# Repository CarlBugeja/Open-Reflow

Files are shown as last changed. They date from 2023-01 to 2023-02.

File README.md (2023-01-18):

# Open-Reflow-Controller-Self-Reflow-PCB-
Shield: [][cc-by-sa]
A controller for self-reflowing PCBs
This work is licensed under a
[Creative Commons Attribution-ShareAlike 4.0 International License][cc-by-sa].

[][cc-by-sa]

[cc-by-sa]: http://creativecommons.org/licenses/by-sa/4.0/
[cc-by-sa-image]: https://licensebuttons.net/l/by-sa/4.0/88x31.png
[cc-by-sa-shield]: https://img.shields.io/badge/License-CC%20BY--SA%204.0-lightgrey.svg

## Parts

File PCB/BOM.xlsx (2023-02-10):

Comment | Description | Designator | Footprint | LibRef | Quantity
UBC1H470MNS1GS |  | C1 | UBC1H470MNS1GS | UBC1H470MNS1GS | 1
22uF |  | C2 | CAPAE4343X55M | CAP* | 1
10nF |  | C3, C6, C13, C15 | RESC1608X04N | CAP | 4
100nF |  | C4, C5, C7, C9, C12, C14, C16 | RESC1608X04N | CAP | 7
1uF |  | C8 | RESC1608X04N | CAP | 1
12pF |  | C10, C11 | RESC1608X04N | CAP | 2
'LTST-C190KFKT |  | D1, D2 | RESC1608X04N | LED | 2
691508110302 | Serie 5081 - 3.50 mm Horizontal Entry SMT with Rising Cage Clamp WR-TBL, 2 pin | H2, H3 | 691508110302 | CMP-1502-02490-1 | 2
10118193-0001LF | Micro USB B Type Receptacle, -55 to 85 degC, 5-Pin SMD, RoHS, Tape and Reel | J1 | FCI-10118193-0001LF-5_V | CMP-2000-05119-1 | 1
LI0805H151R-10 | Chip Beads for Signal Filtering, 0.15 Ohms, -40 to 125 degC, 2-Pin SMD, RoHS, Tape and Reel | L1, L2 | LIRD-LI0805H151R-10-2_V | CMP-2000-05195-1 | 2
BSC0906NS | N-Channel OptiMOS Power-MOSFET, 30 V VDS, 63 A ID, -55 to 150 degC, PG-TDSON-8-1, Reel, Green | Q1 | INF-PG-TDSON-8-1_V | CMP-1090-00064-1 | 1
22 |  | R1, R3 | RESC1608X04N | RES | 2
150 |  | R2, R4 | RESC1608X04N | RES | 2
100 |  | R5, R9, R13 | RESC1608X04N | RES | 3
10k |  | R6, R7, R8, R10 | RESC1608X04N | RES | 4
DNP | 'RC0402JR-0710KL | R11, R12 | RESC1005X40X25ML5T10 | CMP-2002-07915-2 | 2
PTS815 SJK 250 SMTR LFS |  | SW1, SW2 | PTS815 SJK 250 SMTR LFS | PTS815 SJK 250 SMTR LFS | 2
TL750M05CKVURG3 | Single Output LDO, 750 mA, Fixed 5 V Output, 6 to 26 V Input, with Low IQ, 3-pin PFM (KVU), 0 to 125 degC, Green (RoHS & no Sb/Br) | U1 | KVU0003A_M | CMP-0395-01077-2 | 1
ATmega32U4-AU | 8-bit AVR Microcontroller, 2.7-5.5V, 16MHz, 32KB Flash, 1KB EEPROM, 2.5KB SRAM, USB Controller, 44-pin TQFP, Industrial Grade (-40°C to 85°C), Ext Osc | U2 | 44ML_M | CMP-0095-00285-2 | 1
MCP9600-E/MX | IC THERMOCOUPLE TO I2C 20MQFN | U3 | FP-C04-186-MFG | CMP-06290-000001-1 | 1
TSX-3225 16.0000MF09Z-AC0 | CRYSTAL 16.0000MHZ 9PF SMD | Y1 | FP-TSX-3225-MFG | CMP-36405-000014-1 | 1

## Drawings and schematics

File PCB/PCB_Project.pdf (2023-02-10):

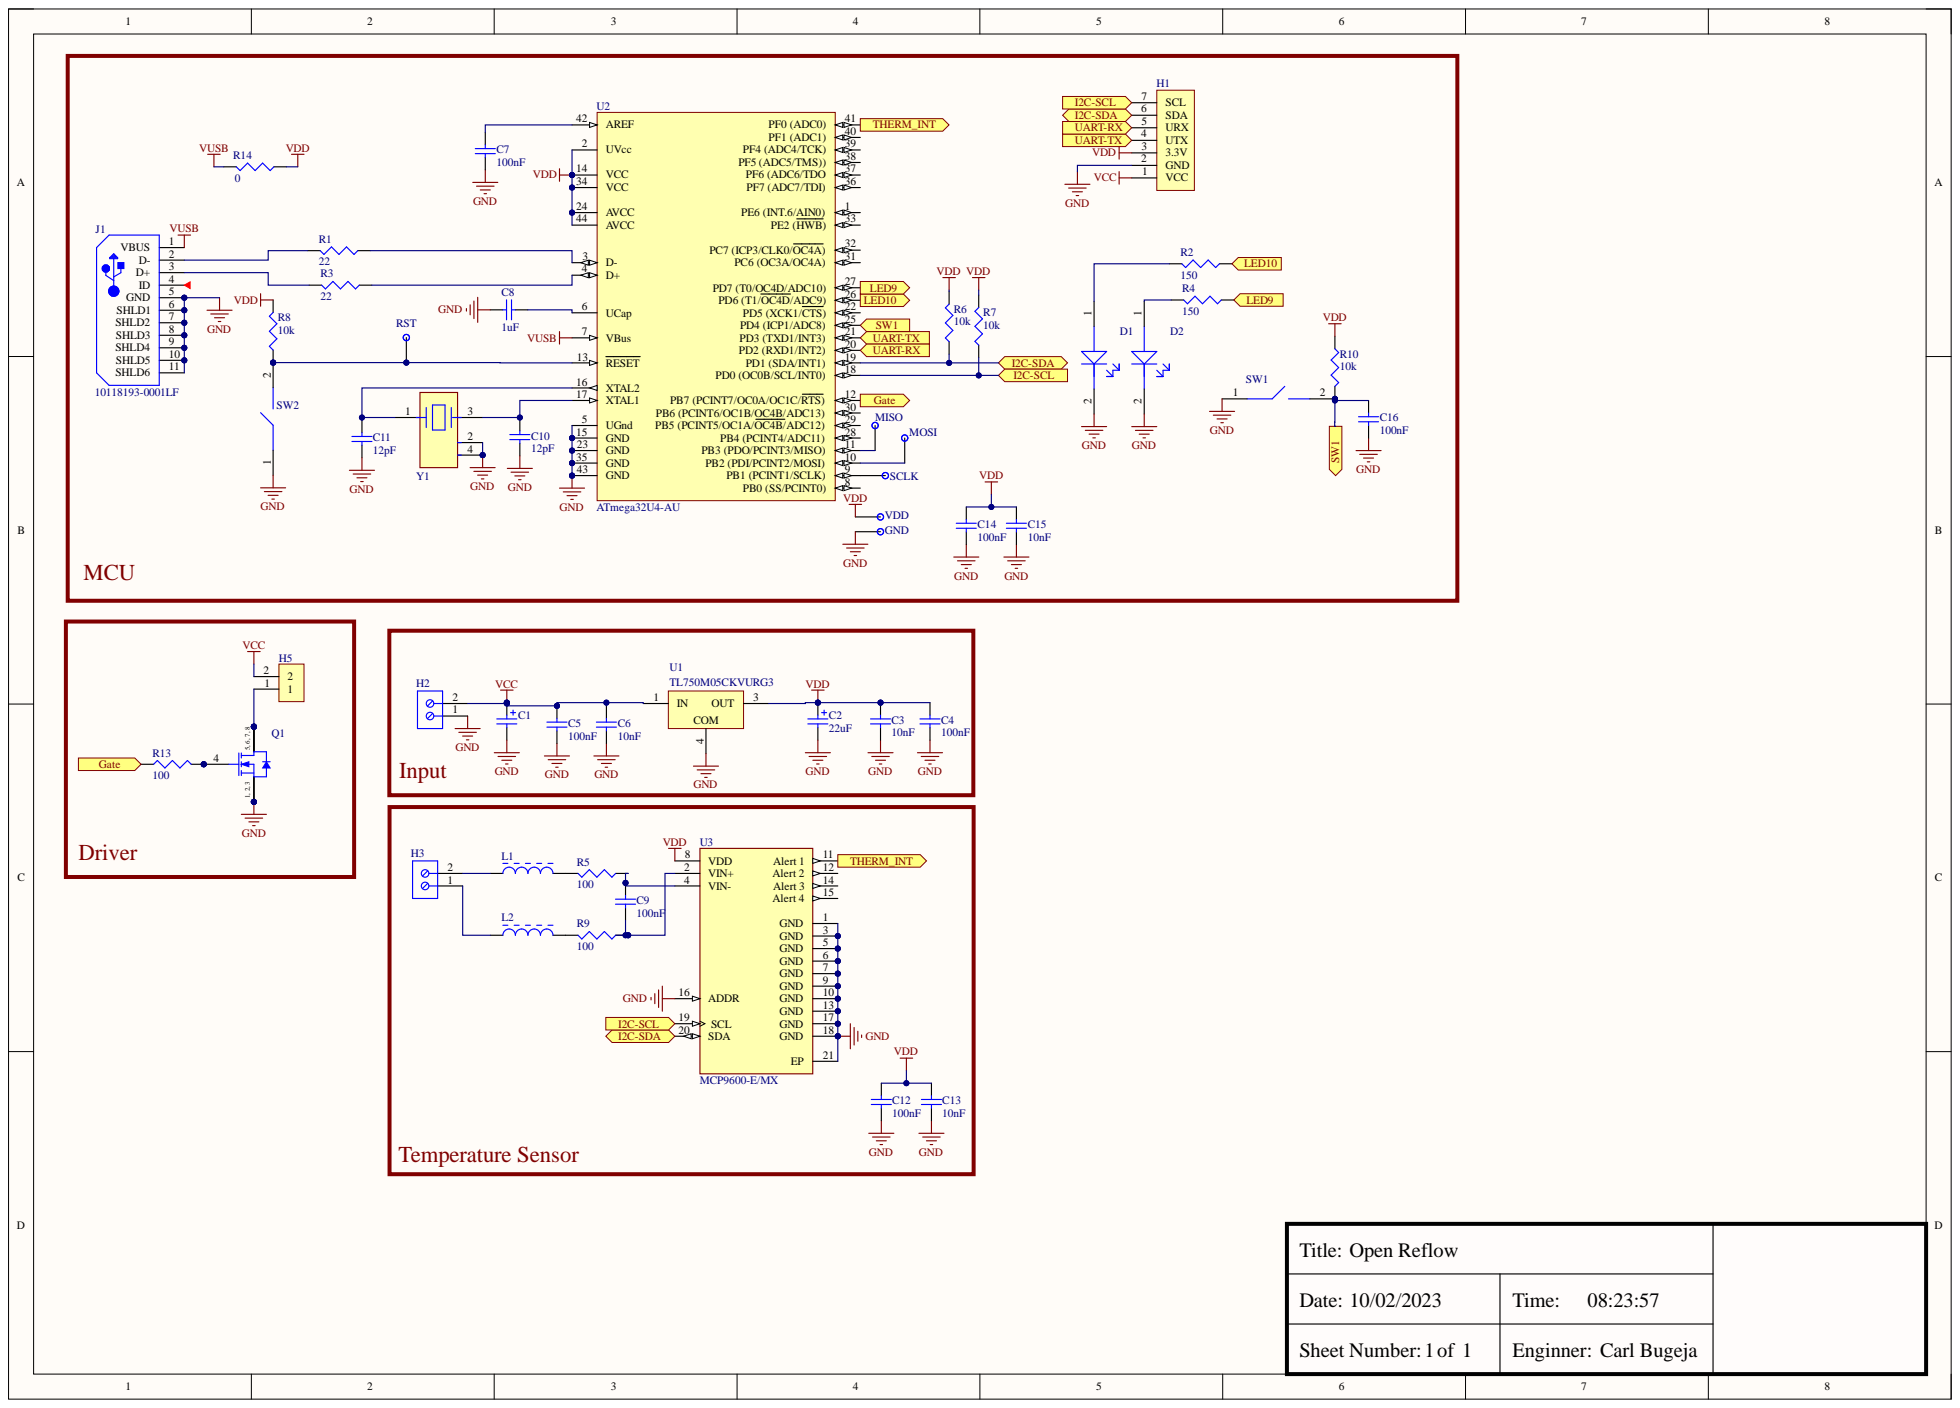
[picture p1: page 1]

Title: Open Reflow

Date: 10/02/2023 | Time: 08:23:57

Sheet Number: | Enginner: Carl Bugeja

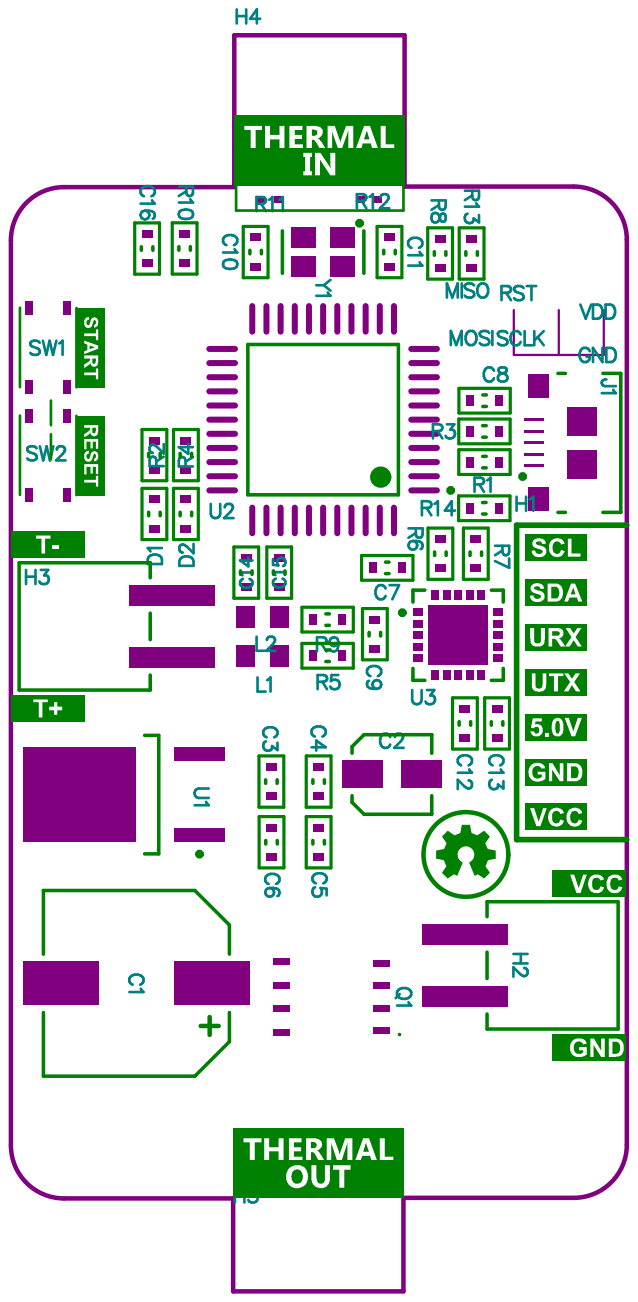
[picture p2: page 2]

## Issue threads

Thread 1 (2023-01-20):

Carl,

robouden, 2023-01-20:

robouden, 2023-01-20:
Carl,

Found a way to convert the files to Kicad with importing the Altium files in the standalone version of KiCad nightly schematic and PCB editor and the combining those in a new KiCad file.  Feel free to add it to the repo for other users to be explored.

Regards,
rob Oudendijk

[PCB_Project_with_KiCad files.zip](https://github.com/CarlBugeja/Open-Reflow/files/10465966/PCB_Project_with_KiCad.files.zip)

robouden, 2023-01-20:
Carl,

Found a way to convert the files to KiCad with importing the Altium files in the standalone version of KiCad nightly schematic and PCB editor and the combining those in a new KiCad file. Feel free to add it to the repo for other users to be explored.

Regards,
rob Oudendijk
[Open-reflow.zip](https://github.com/CarlBugeja/Open-Reflow/files/10466504/Open-reflow.zip)
[Open-reflow.zip](https://github.com/CarlBugeja/Open-Reflow/files/10466525/Open-reflow.zip)

CarlBugeja, 2023-01-21:
Hi Rob

Thank you so much for this! I have uploaded the files giving you credit

gadjet, 2023-01-22:
Hi, Thanks for doing the KiCad conversion, I'm running 6.0.9 and it will not open the files due to it being for a later version of KiCad, can you tell us what's the min. version required?

Thanks again,
Phil

robouden, 2023-01-23:
Phil,

I normally run the KiCad nightly build. That way I can give back to the team with feedback on their product. My policy is to improve open source collaboration. You can install stable and nightly builds on the same computer.

In a few days, I will add the 3d models to the files.

Regards,
Rob Oudendijk

robouden, 2023-01-23:
Phil and Carl,

Attached to this message is the KiCad (needs KiCad Nightly build) converted files and 3d models.
Maybe still requires some cleanup on
[Open-Reflow-main.zip](https://github.com/CarlBugeja/Open-Reflow/files/10477577/Open-Reflow-main.zip)
the graphics placement etc.
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

Regards,
Rob Oudendijk

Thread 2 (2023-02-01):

Kicad version will not open with Kicad 6.0

bmentink, 2023-02-01:
Version 6 is the latest on MacOS, so not sure how to fix this.

bmentink, 2023-02-01:
I even upgraded to the latest nightly, but still your files will not open. The error is:

To open it you will need to upgrade
KiCad to a version dated 20221206 or later

Whch is strange, as the Macos version IS newer ..  Version: (6.0.11-0), release build

eabase, 2023-02-11:
Perhaps make sure all installation artifacts have been removed?

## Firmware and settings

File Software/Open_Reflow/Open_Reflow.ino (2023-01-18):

#include <Wire.h>
#include <Adafruit_I2CDevice.h>
#include <Adafruit_I2CRegister.h>
#include "Adafruit_MCP9600.h"

#define I2C_ADDRESS (0x60)

#define OR_MOSFET 11U
#define OR_GLED 6U
#define OR_RLED 12U
#define OR_SW 4U

#define PID_Kp 75
#define PID_Ki 5
#define PID_Kd 30

uint16_t OR_RTempArray[271U] = {20U,  20U,  21U,  22U,  23U,  23U,  24U,  25U,  26U,  27U,  27U,  28U,  29U,  30U,  30U,  31U,  32U,  33U,  34U,  34U,  35U,  36U,  37U,  37U,  38U,  39U,  40U,  41U,  41U,  42U,  43U,  44U,  44U,  45U,  46U,  47U,  48U,  48U,  49U,  50U,  51U,  51U,  52U,  53U,  54U,  55U,  55U,  56U,  57U,  58U,  58U,  59U,  60U,  61U,  62U,  62U,  63U,  64U,  65U,  65U,  66U,  67U,  68U,  69U,  69U,  70U,  71U,  72U,  72U,  73U,  74U,  75U,  76U,  76U,  77U,  78U,  79U,  79U,  80U,  81U,  82U,  83U,  83U,  84U,  85U,  86U,  86U,  87U,  88U,  89U,  90U,  90U,  90U,  91U,  91U,  92U,  92U,  93U,  93U,  93U,  94U,  94U,  95U,  95U,  96U,  96U,  97U,  97U,  97U,  98U,  98U,  99U,  99U,  100U, 100U, 101U, 101U, 101U, 102U, 102U, 103U, 103U, 104U, 104U, 105U, 105U, 105U, 106U, 106U, 107U, 107U, 108U, 108U, 109U, 109U, 109U, 110U, 110U, 111U, 111U, 112U, 112U, 113U, 113U, 113U, 114U, 114U, 115U, 115U, 116U, 116U, 117U, 117U, 117U, 118U, 118U, 119U, 119U, 120U, 120U, 121U, 121U, 121U, 122U, 122U, 123U, 123U, 124U, 124U, 125U, 125U, 125U, 126U, 126U, 127U, 127U, 128U, 128U, 129U, 129U, 130U, 130U, 130U, 130U, 131U, 131U, 131U, 131U, 132U, 132U, 132U, 132U, 133U, 133U, 133U, 134U, 134U, 134U, 134U, 135U, 135U, 135U, 135U, 136U, 136U, 136U, 136U, 137U, 137U, 137U, 138U, 138U, 139U, 140U, 141U, 142U, 143U, 144U, 145U, 146U, 147U, 147U, 148U, 149U, 150U, 151U, 152U, 153U, 154U, 155U, 156U, 156U, 157U, 158U, 159U, 160U, 161U, 162U, 163U, 164U, 165U, 164U, 163U, 162U, 161U, 160U, 159U, 158U, 157U, 156U, 156U, 155U, 154U, 153U, 152U, 151U, 150U, 149U, 148U, 147U, 147U, 146U, 145U, 144U, 143U, 142U, 141U, 140U, 139U, 138U, 138U};

Adafruit_MCP9600 mcp;
bool OR_Flag = false;
bool LED_flag = false;
double OR_Time0 = 0.0, OR_Time = 0.0, PID_TimeChange = 0.0, PID_TimeLast  = 0.0, PID_Error = 0.0, PID_Intg = 0.0, PID_Derv = 0.0, PID_ErrorLast = 0.0;
uint16_t OR_TimeULast = 0U;

void setup() {
  pinMode(OR_MOSFET, OUTPUT);
  pinMode(OR_GLED, OUTPUT);
  pinMode(OR_RLED, OUTPUT);
  pinMode(OR_SW, INPUT);
  
  analogWrite(OR_RLED, 0); /*Disable PWM*/
  analogWrite(OR_MOSFET, 0); /*Disable PWM*/
    
  Serial.begin(19200);
//  while (!Serial){
//     delay(10);
//  }
  /*while the serial stream is not open, do nothing*/
  Serial.println("OPEN REFLOW");
  Serial.println("Starting Up the Board");
  
  analogWrite(OR_RLED, 200); /*Disable PWM*/
  delay(500);
  if(! mcp.begin(I2C_ADDRESS)){
    Serial.println("Sensor not found. Check wiring!");
    while(1){}
  }
  else{
    Serial.println("Sensor Found!");
  }

  mcp.setADCresolution(MCP9600_ADCRESOLUTION_18);
  mcp.setThermocoupleType(MCP9600_TYPE_K);
  mcp.setFilterCoefficient(3);
  mcp.enable(true);

  Serial.print("Ambient Temperature(°C):"); Serial.println(mcp.readAmbient());

  analogWrite(OR_RLED, 0); /*Disable PWM*/      
  digitalWrite(OR_GLED, HIGH); 
}

void loop() {
  double OR_Temp = mcp.readThermocouple();
  double OR_Ambient = mcp.readAmbient();
  double OR_RTemp = 0.0;
  double OR_ROut = 0U;
         
  if((!digitalRead(OR_SW))||(OR_Flag == true)){    
      digitalWrite(OR_GLED, LOW);   
      delay(1);
      if(OR_Flag == false){
        OR_Time0 = ((double)millis())/1000;/*Read intial time*/
        OR_Flag = 1;
      }
      else{
        /*SPID_Kip*/
      }        

      OR_Time = (((double)millis())/1000)-OR_Time0;/*Read current time*/       
      uint16_t OR_TimeU = (uint16_t)OR_Time;/*convert to integer*/

      if (OR_TimeU >= 270U){
        OR_Flag = 0; /*Cool off*/           
      }      
      else{
        OR_RTemp = OR_RTempArray[OR_TimeU];/*Get desired Temperature*/
      }
      if(OR_TimeU != OR_TimeULast){
        OR_TimeULast = OR_TimeU;
        Serial.print("Board Temperature:"); Serial.println(OR_Temp);/*Print current temperature of the board*/
        Serial.print("Desired Temperature:"); Serial.println(OR_RTemp); /*Print desired temperature of the board*/
        //Serial.print("Output:"); Serial.println((int)OR_ROut);
        //Serial.print("Delta:"); Serial.println(OR_RTemp-OR_Temp);
      }
      else{
        /*Skip*/
      }
      
      /*Compute PID on sensed temperature*/
      PID_TimeChange = OR_Time - PID_TimeLast;    
      PID_Error = OR_RTemp - OR_Temp;
      PID_Intg = PID_Intg + (PID_Error * PID_TimeChange);
      PID_Derv = (PID_Error - PID_ErrorLast)/PID_TimeChange;
      OR_ROut = (PID_Kp*PID_Error) + (PID_Ki*PID_Intg) + (PID_Kd*PID_Derv);              
      if(OR_ROut > 255.0){
        OR_ROut = 255.0;
      }
      if(OR_ROut < 0.0){
        OR_ROut = 0.0;
      }  
      PID_ErrorLast = PID_Error;
      PID_TimeLast = OR_Time; 
       
      analogWrite(OR_MOSFET, (int)OR_ROut);
      analogWrite(OR_RLED, (int)OR_ROut); 
  }
  else{
    /*wait*/
      analogWrite(OR_RLED, 0); /*Disable PWM*/
    analogWrite(OR_MOSFET, 0); /*Disable PWM*/
    delay(500);
    if(OR_Temp >= (OR_Ambient + 2.0)){  
      Serial.print("Board cooling off. Temperature at "); Serial.print(OR_Temp); Serial.print("°C Waiting to reach "); Serial.print(OR_Ambient); Serial.println("°C"); 
      delay(500);
      digitalWrite(OR_GLED, HIGH); 
      delay(500);
      digitalWrite(OR_GLED, LOW); 
    }
    else{
      delay(1000);
      if(!digitalRead(OR_GLED)){
        digitalWrite(OR_GLED, HIGH); 
        Serial.println("Press START to Reflow");
        PID_Intg = 0;
        PID_Error = 0;
        PID_Derv = 0;
        PID_ErrorLast = 0;
        PID_TimeLast = 0;
      }
      else{
        /*Wait*/
      }
    }    
  }
}

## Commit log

2023-01-21 Add files via upload
    Altium files converted to kicad by @robouden
2023-02-10 Add files via upload
    BOM, Schematics, Layout
    [BOM.xlsx]

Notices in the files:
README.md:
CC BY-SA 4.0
